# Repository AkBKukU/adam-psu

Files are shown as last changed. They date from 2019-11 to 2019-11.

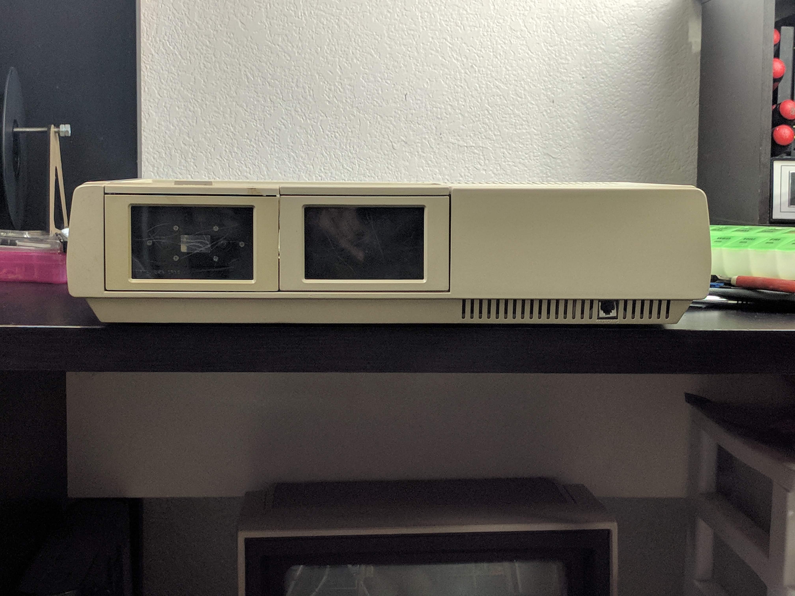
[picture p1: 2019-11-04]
doc/IMG_20191101_171837.jpg

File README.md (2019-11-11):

# Coleco Adam Internal PSU

The Coleco Adam originally shipped with a printer that contained the entire PSU 
for the device. It generated 12V, 5V, & -5V DC voltages for the system to run on.
Now it is increasingly difficult to find the printer to go along with the 
system. This renders them unusable.

This project is an internal PSU that can be mounted inside the standalone 
Coleco Adam. If you have an Expansion Module #3 version of the Adam, it can be
used outside of the system as well.

## Installation 

This part was designed specifically to be non-destructive and once you have an
assembled part, does not require any soldering. The DB9 connector on the standalone
Adam is on a small cabled PCB. This board mounts in place of that and you 
internally connect that cable to the new PSU. Optionally, you could cut or 
desolder the DB9 connector and directly bridge across to the available pads.

For use with the Expansion Module #3 version of the Adam, the board can be 
externally plugged into the system. Based on feedback, this is assumed to be 
a much less common model and the design hasn't been optimized for this use. You 
may need to extend the DB9 connection to have enough clearance. A solid DB9
male to female adapter is encouraged over a cable for its better current 
capacity. If you do opt to use a DB9 extension cable **make sure it is not a 
null modem cable!**. Pins 3 & 3 on a null modem cable are swapped which will 
swap 12V and 5V going to your system which will **severely damage** crucial 
components.

## Functionality

This power supply is fundamentally a multi voltage DC-DC regulator. It takes in
a 12V 3A power source and while passing through the 12V also generates 5V and
-5V. The system itself has the following maximum power ratings:

 - 5V - 2.75A
 - -5V - 0.2A
 - 12VI - 0.6A
 - 12VL - 0.3A

(*Taken from page 49 of the Adam Technical reference manual*)

The 12V rail is split between inductive and logic loads on the system side. `D1`
allows for potentially high voltages to be recirculated but due to the shared
ground at this time I'm not sure how useful this really is.

This power supply is capable of supplying the following with the DC-DC 
regulators:

 - 5V - 5A
 - -5V - 1A

These higher output capabilities combined with the ability to change the 12V 
external power source should allow all potential accessories to have sufficient 
power. The original maximum power rating is in total ~25.2W, using a 3A 12V 
AC-DC converter provides ample headroom for DC regulations losses.

## Design

This regulator is made using SMPS Buck regulators to reduce the 12V input to 5V 
and -5V. The -5V source is a standard buck regulators being used in a negative 
configuration. Care has been taken in the design and parts selection to maintain
as much efficiency as possible. Despite this there will be power dissipation 
still and the board layout has taken this into consideration providing large
copper pours where possible. Heat sinking should not be necessary as the parts
should be, on average, drawing less than half of their maximum current in 
addition to the PCB cooling.

The physical parts selection for this as well as the layout design has kept in 
mind the ability to hand solder the parts. However, outside of the I/O, all 
parts are SMD and go down to 0603 sized passives. It is recommend that you have
a solid background in soldering, but this is not an especially difficult SMD 
board to assemble. `U2`, is an SOIC-8 with a thermal pad which will likely be 
the part that will give beginners the most difficulty. Recommended steps are:

 - Lightly tin the thermal pad
 - Apply flux
 - Place the part down, checking orientation
 - Solder opposing corner pins
 - Apply heat to the underside of the board while also applying pressure to the 
   part
 - Finish soldering remaining pins

## Availability, BOM, and Ordering

I will be producing these indefinitely and making them available for purchase.
They will be available on my website once I have assembled and validated the 
design.

The BOM is stored as extra fields in the KiCad schematic and can be exported
from there. It is also included as a CSV file with the non-orderable parts 
removed.

I have also created BOMs on Digi-Key and Mouser as shared carts that you can 
order directly:

Digi-Key: https://www.digikey.com/short/p0tbzh
Mouser: https://www.mouser.com/ProjectManager/ProjectDetail.aspx?AccessID=6486fe3deb 

**BOM Errata**: For v0.1 boards R4 needs to be changed to 1k instead of `0k. 
The BOM carts have not been updated to reflect this yet.

The parts selection vary slightly between vendors. Equivalent performance low
cost parts were selected in each case.

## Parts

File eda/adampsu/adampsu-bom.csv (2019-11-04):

Reference | Quantity | Value | Footprint | Datasheet | dk | mfr | mouser | maxV | rating
C11 | 1 | 2200pF | Capacitor_SMD:C_0603_1608Metric_Pad1.05x0.95mm_HandSolder | https://api.kemet.com/component-edge/download/datasheet/C0603C222K5RAC7411.pdf | 399-17586-1-ND | C0603C222K5RAC7411 | 80-C0603C222K5R7411 | 50 | XR7
C12 | 1 | 22pF | Capacitor_SMD:C_0603_1608Metric_Pad1.05x0.95mm_HandSolder | http://datasheets.avx.com/X7RDielectric.pdf | 478-6204-1-ND | 06035C220JAT2A | 581-06035C220JAT2A | 50 | XR7
C16 C5 | 2 | 0.1uF | Capacitor_SMD:C_0603_1608Metric_Pad1.05x0.95mm_HandSolder | http://www.samsungsem.com/kr/support/product-search/mlcc/CL10F104ZB8NNNC.jsp | 1276-1012-2-ND | CL10F104ZB8NNNC | 603-CC603KRX7R9BB104 | 25 | XR7
C17 C18 C13 C19 C14 C20 | 6 | 22uF | Capacitor_SMD:C_1206_3216Metric_Pad1.42x1.75mm_HandSolder | ~ | 1276-6780-1-ND | EMK316ABJ226ML-T | 963-EMK316ABJ226ML-T
C2 C1 | 2 | 10uF |  | ~ | 490-10498-1-ND | GRM21BC81C106KE15L | 81-GRM21BC81C106KE5L
C3 | 1 | 100uF | Capacitor_Tantalum_SMD:CP_EIA-7343-30_AVX-N_Pad2.25x2.55mm_HandSolder | http://datasheets.avx.com/TAJ_AUTO.pdf | 1189-1659-1-ND | TAJD107K016TNJV | 581-TAJD107K016TNJV | 16 | XR7
C7 C4 | 2 | 4.7uF | Capacitor_SMD:C_1206_3216Metric_Pad1.42x1.75mm_HandSolder | https://ds.yuden.co.jp/TYCOMPAS/ut/detail?pn=UMK316AB7475KL-T%20%20&u=M | 490-14466-2-ND | GRM21BR71C475KE51L | 81-GRM21BR71C475KE1L | 50 | XR7
C8 C10 C15 | 3 | 0.01uF | Capacitor_SMD:C_0603_1608Metric_Pad1.05x0.95mm_HandSolder | https://api.kemet.com/component-edge/download/datasheet/C0603C103M5RACTU.pdf | 399-7842-1-ND | C0603C103M5RACTU | 80-C0603C103M5R |  | XR7
C9 C6 | 2 | 0.1uF | adampsu:C_0508_1220Metric_Pad1.40x1.15mm_HandSolder | https://search.murata.co.jp/Ceramy/image/img/A01X/G101/ENG/LLL216R71E104MA01-01.pdf | 490-4346-1-ND | LLL216R71E104MA01L | 81-LLL216R71E104MA1L | 25 | XR7
D1 D2 | 2 | D_Schottky | adampsu:D_SOD-128 | https://www.mouser.com/datasheet/2/916/PMEG4050EP-1320387.pdf | 1727-5842-1-ND | PMEG4050EP,115 | 963-EMK325B7226MM-TR | 40
J1 | 1 | Barrel_Jack_Switch | adampsu:BarrelJack_CUI_PJ-047AH_Horizontal | https://www.cuidevices.com/product/resource/pj-047ah.pdf | CP-047AH-ND | PJ-047AH | 490-PJ-047AH
J2 | 1 | Conn_2Rows-09Pins | Connector_PinHeader_2.54mm:PinHeader_2x05_P2.54mm_Vertical | ~ | 1849-1002-ND | PR20205VBDN
J3 | 1 | DB9_Female | Connector_Dsub:DSUB-9_Female_Vertical_P2.77x2.84mm_MountingHoles | http://www.assmann-wsw.com/fileadmin/datasheets/ASS_4885_CO.pdf | AE10928-ND | A-DF 09 PP/Z | 636-171-009-203L001
L1 L2 | 2 | 4.7uH | adampsu:L_11.5x10.3_H4.8 | http://productfinder.pulseeng.com/products/datasheets/P769.pdf | 553-3001-1-ND | PA4342.472NLT | 673-PA4342.472NLT |  | 15.5mOhm
PC1 | 1 | PlungerCap | adampsu:PlungerCap-4JWHT | https://www.digikey.com/product-detail/en/e-switch/4JWHT/EG1077-ND/45809 | EG1077-ND | 4JWHT | 612-4J-WH
Q1 | 1 | BUK7880-55A_CUX | Package_TO_SOT_SMD:SOT-223-3_TabPin2 | https://assets.nexperia.com/documents/data-sheet/BUK7880-55A.pdf | 1727-2222-1-ND | BUK7880-55A/CUX | 771-BUK7880-55A/CUX
R10 | 1 | 1.96k | Resistor_SMD:R_0603_1608Metric_Pad1.05x0.95mm_HandSolder | http://www.yageo.com/documents/recent/PYu-RC_Group_51_RoHS_L_10.pdf | 311-1.96KHRCT-ND | RC0603FR-071K96L | 603-RC0603FR-071K96L
R11 | 1 | 54.9k |  | ~ |  | CR0603-FX-5492ELF | 652-CR0603FX-5492ELF
R3 | 1 | 1k | Resistor_SMD:R_0603_1608Metric_Pad1.05x0.95mm_HandSolder | http://www.yageo.com/documents/recent/PYu-RC_Group_51_RoHS_L_10.pdf | 311-1.0KGRCT-ND | RC0603JR-071KL | 603-RC0603JR-071KL
R4 R1 R2 | 3 | 10k | Resistor_SMD:R_0603_1608Metric_Pad1.05x0.95mm_HandSolder | http://www.yageo.com/documents/recent/PYu-RC_Group_51_RoHS_L_10.pdf | 311-10KGRCT-ND | RC0603JR-0710KL | 603-RC0603JR-0710KL
R5 | 1 | 665k | Resistor_SMD:R_0603_1608Metric_Pad1.05x0.95mm_HandSolder | http://www.yageo.com/documents/recent/PYu-RC_Group_51_RoHS_L_10.pdf | 311-665KHRCT-ND | RC0603FR-07665KL | 603-RC0603FR-07665KL
R6 | 1 | 130k | Resistor_SMD:R_0603_1608Metric_Pad1.05x0.95mm_HandSolder | http://www.koaspeer.com/catimages/Products/RK73B/RK73B.pdf | 2019-RK73B1JTTD134JCT-ND | RK73B1JTTD134J | 660-RK73B1JTTD134J
R7 | 1 | 37.4k | Resistor_SMD:R_0603_1608Metric_Pad1.05x0.95mm_HandSolder | http://www.yageo.com/documents/recent/PYu-RC_Group_51_RoHS_L_10.pdf | 311-37.4KHRCT-ND | RC0603FR-0737K4L | 603-RC0603FR-0737K4L
R8 | 1 | 51.1 | Resistor_SMD:R_0603_1608Metric_Pad1.05x0.95mm_HandSolder | http://www.yageo.com/documents/recent/PYu-RC_Group_51_RoHS_L_10.pdf | 311-51.1HRCT-ND | RC0603FR-0751R1L | 603-RC0603FR-0751R1L
R9 | 1 | 10.2k | Resistor_SMD:R_0603_1608Metric_Pad1.05x0.95mm_HandSolder | https://www.seielect.com/catalog/sei-rmcf_rmcp.pdf | RMCF0603FT10K2CT-ND | RMCF0603FT10K2 | 667-ERJ-3EKF1022V
SW1 | 1 | 30V 300mA Latching Switch | adampsu:Switch-LC1258EENP | https://sten-eswitch-13110800-production.s3.amazonaws.com/system/asset/product_line/data_sheet/36/LC.pdf | EG5886-ND | LC1258EENP | 612-LC1258EENP
U1 | 1 | TPS561201 | Package_TO_SOT_SMD:SOT-23-6 | http://www.ti.com/lit/ds/symlink/tps561201.pdf | 296-47885-1-ND | TPS561201DDCR | TPS561201DDCR
U2 | 1 | TPS54531DDAR | Package_SO:TI_SO-PowerPAD-8_ThermalVias | http://www.ti.com/lit/ds/symlink/tps54531.pdf | 296-40801-2-ND | TPS54531DDAR | 595-TPS54531DDAR

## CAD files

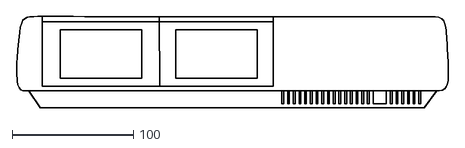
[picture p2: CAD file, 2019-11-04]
doc/adamart.dxf
356.6 x 75.1

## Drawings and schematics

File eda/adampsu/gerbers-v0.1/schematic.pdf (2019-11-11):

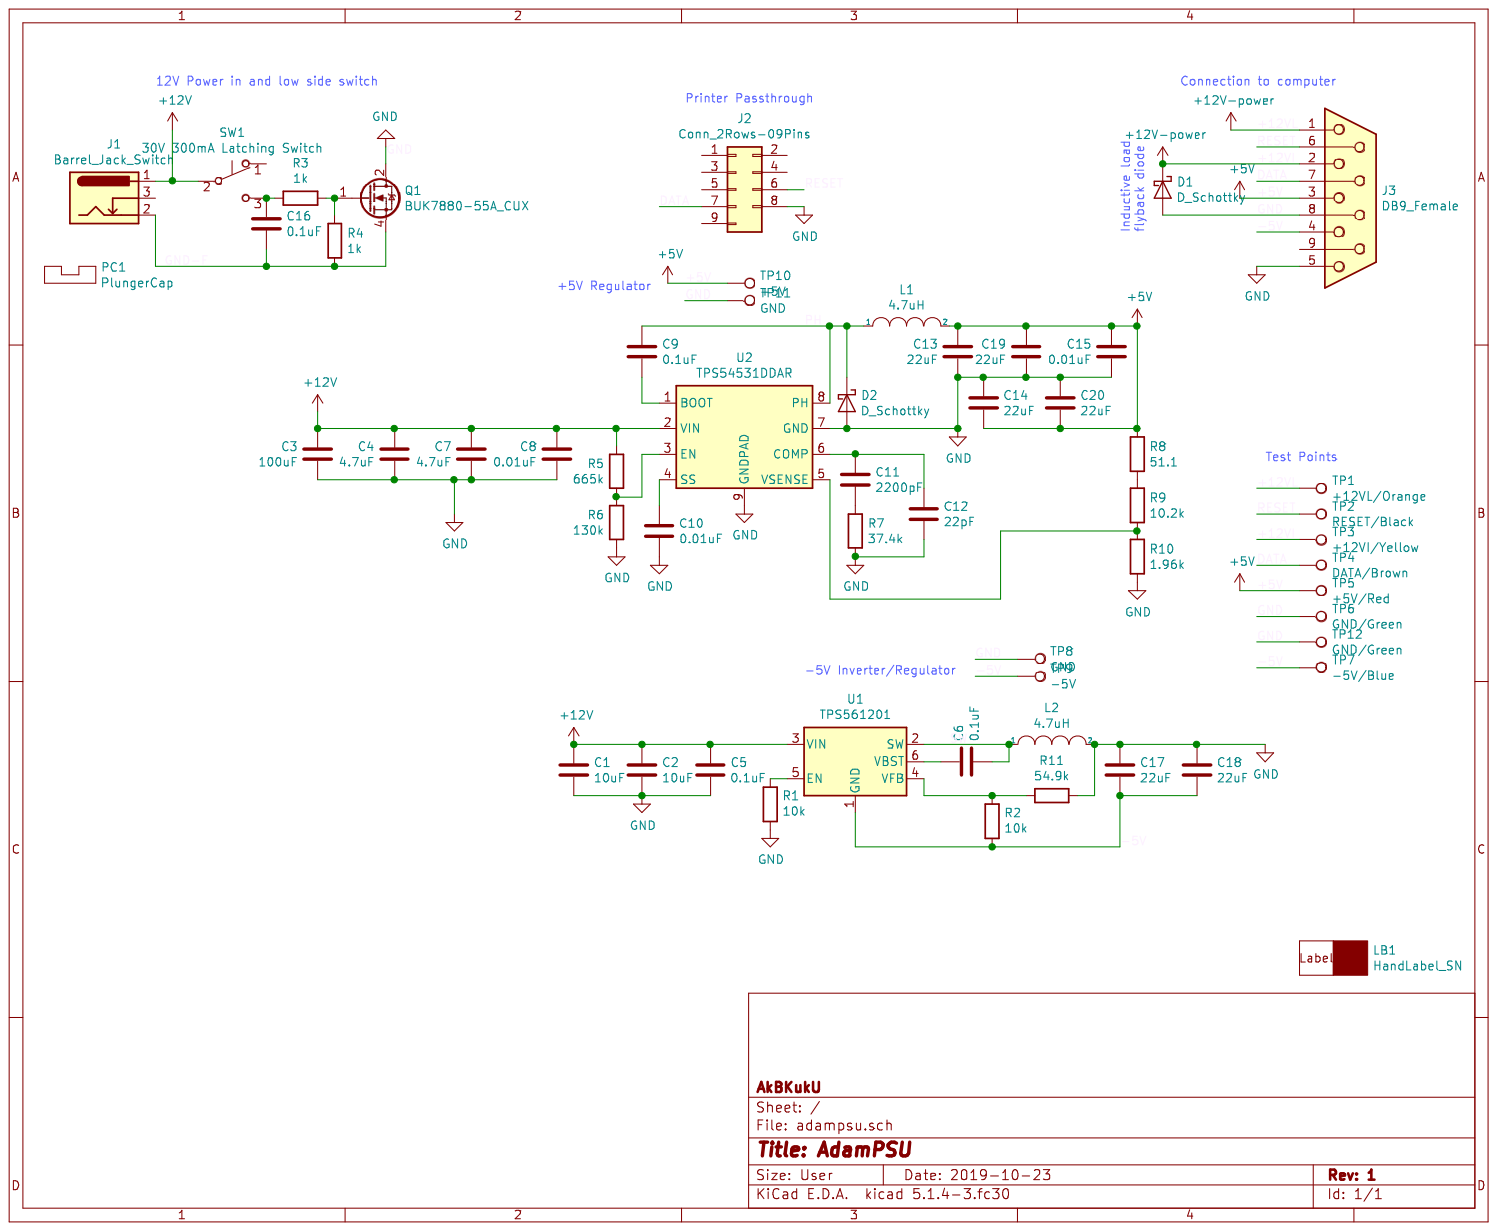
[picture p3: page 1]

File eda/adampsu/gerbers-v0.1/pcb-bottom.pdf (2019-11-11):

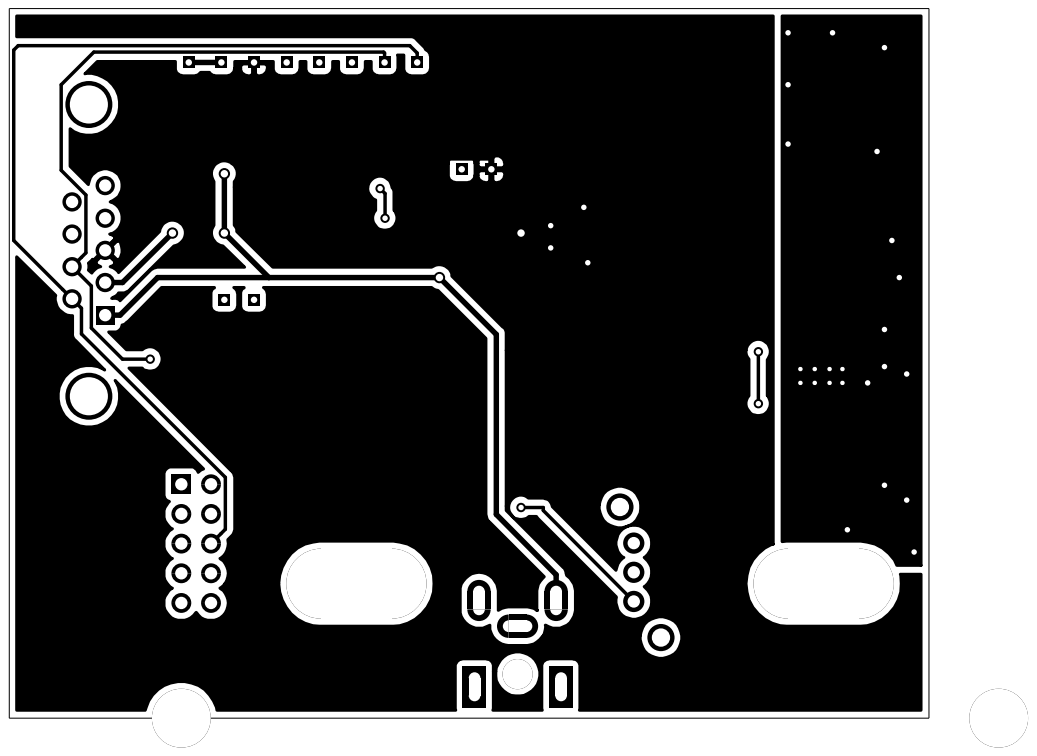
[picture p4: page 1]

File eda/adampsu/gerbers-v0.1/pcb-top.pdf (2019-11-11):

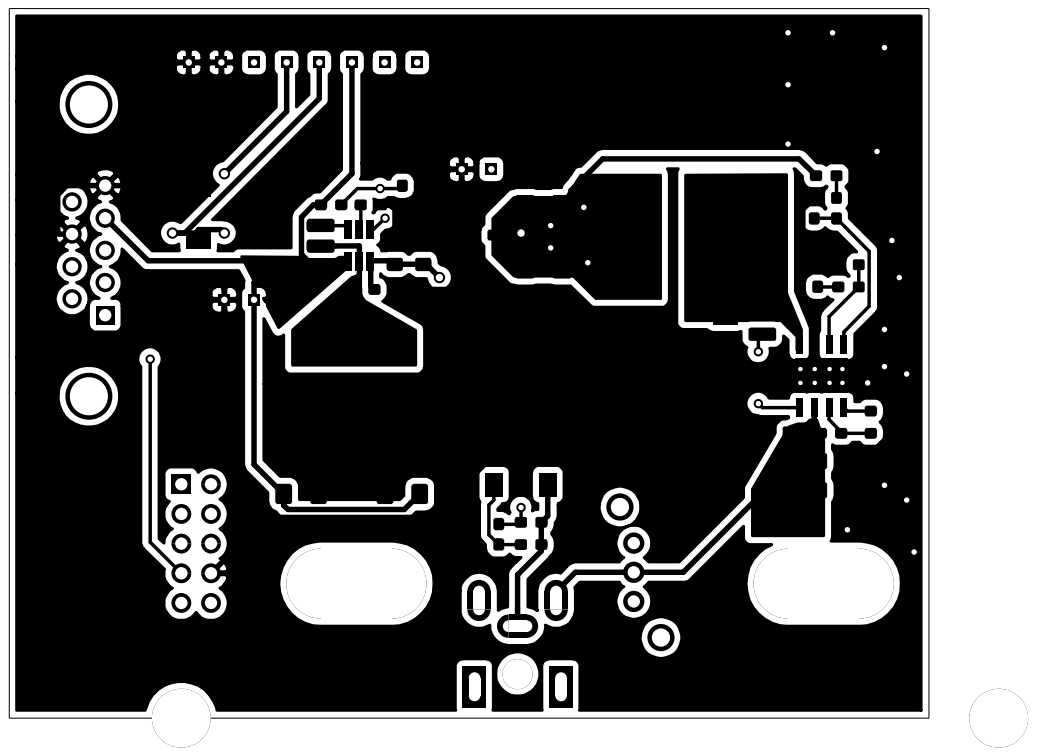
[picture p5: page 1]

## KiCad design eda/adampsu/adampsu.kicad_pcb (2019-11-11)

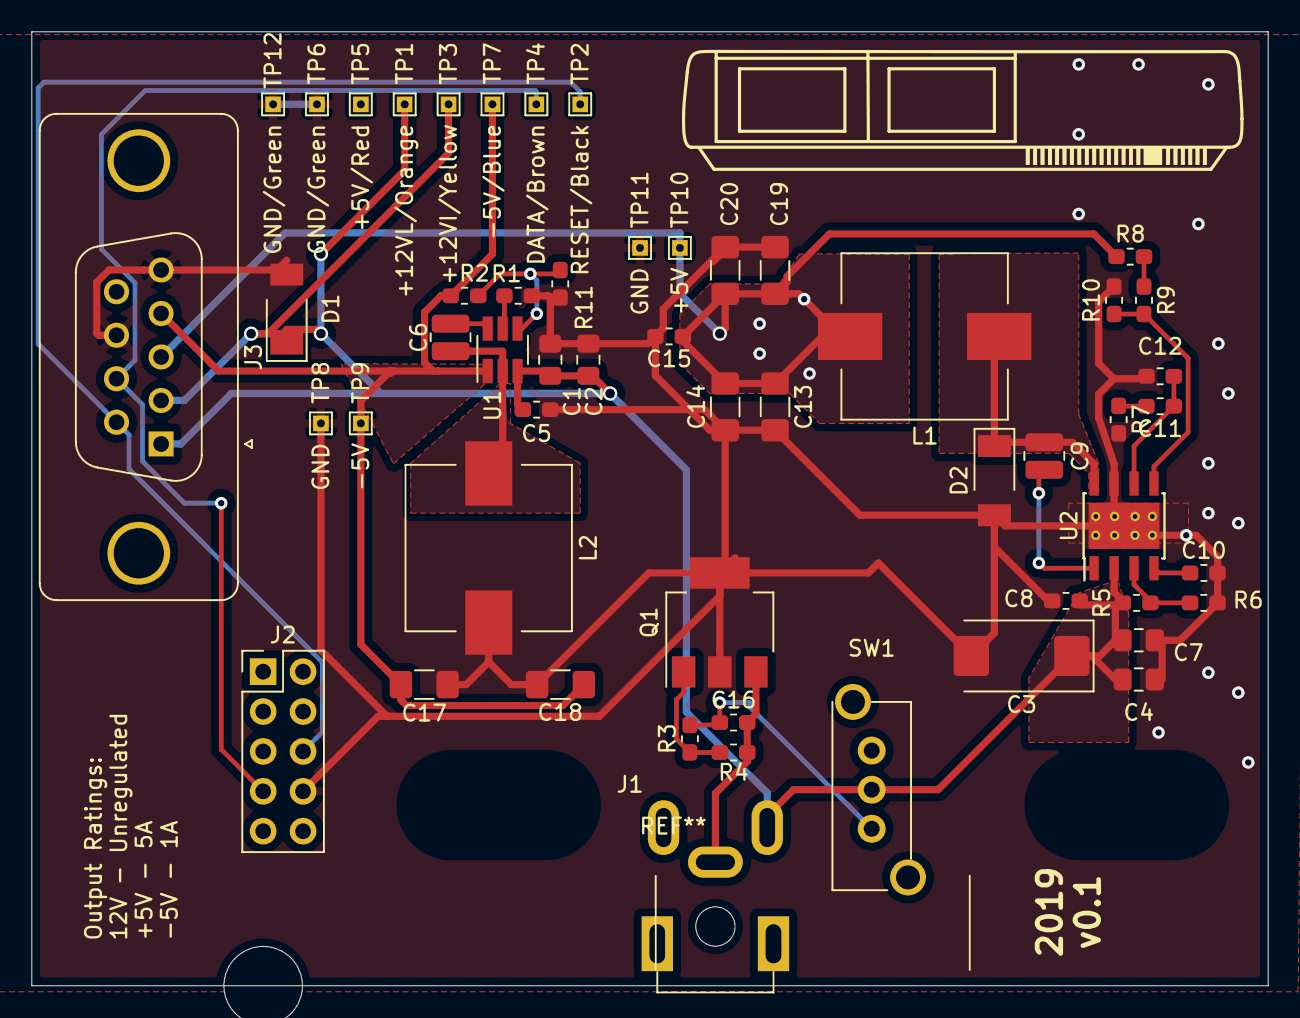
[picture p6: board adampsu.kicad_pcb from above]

Board: 2 copper layers, 78.7 x 60.8 mm, 56 parts (1 on the bottom side), 21 nets.

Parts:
C1, C2: 10uF; C_0805_2012Metric_Pad1.15x1.40mm_HandSolder
C3: 100uF; CP_EIA-7343-43_Kemet-X_Pad2.25x2.55mm_HandSolder
C4, C7: 4.7uF; C_0805_2012Metric_Pad1.15x1.40mm_HandSolder
C5, C16: 0.1uF; C_0603_1608Metric_Pad1.05x0.95mm_HandSolder
C6, C9: 0.1uF; C_0508_1220Metric_Pad1.40x1.15mm_HandSolder
C8, C10, C15: 0.01uF; C_0603_1608Metric_Pad1.05x0.95mm_HandSolder
C11: 2200pF; C_0603_1608Metric_Pad1.05x0.95mm_HandSolder
C12: 22pF; C_0603_1608Metric_Pad1.05x0.95mm_HandSolder
C13, C14, C17, C18, C19, C20: 22uF; C_1206_3216Metric_Pad1.42x1.75mm_HandSolder
D1, D2: D_Schottky; D_SOD-128
J1: Barrel_Jack_Switch; BarrelJack_CUI_PJ-047AH_Horizontal
J2: Conn_2Rows-09Pins; PinHeader_2x05_P2.54mm_Vertical
J3: DB9_Female; DSUB-9_Female_Vertical_P2.77x2.84mm_MountingHoles
L1, L2: 4.7uH; L_11.5x10.3_H4.8
LB1: HandLabel_SN; adamlabel
PC1: PlungerCap; PlungerCap-4JWHT
Q1: BUK7880-55A_CUX; SOT-223-3_TabPin2
R1, R2, R4: 10k; R_0603_1608Metric_Pad1.05x0.95mm_HandSolder
R3: 1k; R_0603_1608Metric_Pad1.05x0.95mm_HandSolder
R5: 665k; R_0603_1608Metric_Pad1.05x0.95mm_HandSolder
R6: 130k; R_0603_1608Metric_Pad1.05x0.95mm_HandSolder
R7: 37.4k; R_0603_1608Metric_Pad1.05x0.95mm_HandSolder
R8: 51.1; R_0603_1608Metric_Pad1.05x0.95mm_HandSolder
R9: 10.2k; R_0603_1608Metric_Pad1.05x0.95mm_HandSolder
R10: 1.96k; R_0603_1608Metric_Pad1.05x0.95mm_HandSolder
R11: 54.9k; R_0603_1608Metric_Pad1.05x0.95mm_HandSolder
SW1: 30V 300mA Latching Switch; Switch-LC1258EENP
TP1: +12VL/Orange; TestPoint_Labeled
TP2: RESET/Black; TestPoint_Labeled
TP3: +12VI/Yellow; TestPoint_Labeled
TP4: DATA/Brown; TestPoint_Labeled
TP5: +5V/Red; TestPoint_Labeled
TP6, TP12: GND/Green; TestPoint_Labeled
TP7: -5V/Blue; TestPoint_Labeled
TP8, TP11: GND; TestPoint_Labeled
TP9: -5V; TestPoint_Labeled
TP10: +5V; TestPoint_Labeled
U1: TPS561201; SOT-23-6_Handsoldering
U2: TPS54531DDAR; TI_SO-PowerPAD-8_ThermalVias

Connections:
+5V: C13.1, C14.2, C15.1, C19.1, C20.2, J3.3, L1.2, R8.1, TP5.1, TP10.1
+12V: C1.1, C2.1, C3.1, C4.1, C5.1, C7.1, C8.1, D1.1, J1.1, J3.1, J3.2, R5.1, SW1.2, TP1.1, TP3.1, U1.3, U2.2
/-5V: C17.2, C18.2, J3.4, R2.1, TP7.1, TP9.1, U1.1
/DATA: J2.7, J3.7, TP4.1
/GND-F: C16.2, J1.2, Q1.3, R4.2
/PH: C9.1, D2.1, L1.1, U2.8
/RESET: J2.6, J3.6, TP2.1
/SW: C6.2, L2.1, U1.2
GND: C1.2, C2.2, C3.2, C4.2, C5.2, C7.2, C8.2, C10.2, C12.2, C13.2, C14.1, C15.2, C17.1, C18.1, C19.2, C20.1, D1.2, D2.2, J2.8, J3.5, J3.8, L2.2, Q1.2, R1.1, R6.2, R7.2, R10.2, R11.1, TP6.1, TP8.1, TP11.1, TP12.1, U2.7, U2.9
unnamed: C6.1, U1.6
unnamed: C9.2, U2.1
unnamed: C10.1, U2.4
unnamed: C11.1, C12.1, U2.6
unnamed: C11.2, R7.1
unnamed: C16.1, R3.2, SW1.3
unnamed: Q1.1, R3.1, R4.1
unnamed: R1.2, U1.5
unnamed: R5.2, R6.1, U2.3
unnamed: R8.2, R9.1
unnamed: R9.2, R10.1, U2.5
unnamed: R2.2, R11.2, U1.4

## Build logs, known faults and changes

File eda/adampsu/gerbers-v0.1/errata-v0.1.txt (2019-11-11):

 
 - Revision needed- 
U2 Power pad not exposed on bottom for manual assembly
R1 connects to GND instead of +12V preventing U1 from turning on
All touch points too small
SW1 power switch on position reversed
SW1 power switch needs more clearance to depress switch

 - Resolvable / non-functional - 
R4 Power switch FET Gate pull down needs to be 1k
R7 RefDes under C11
bottom label text duplicated
C6 1 <-> U1 6 trace width narrow
Q1 Power switch FET detaches GND but non-isolated PSU may still provide a current path

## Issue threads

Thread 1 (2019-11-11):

Q1 Nch FET does not turn off leaving system always on

AkBKukU, 2019-11-11:
The BUK7880 Nch FET in Q1 being used as a low side switch works when tested with individual rails (tested up to 300mA) allowing the 12V PSU GND to be isolated. When installed in the computer it does not fully turn off though allowing the system to stay on.

Vds when on is ~55mV
Vds when off is 12V

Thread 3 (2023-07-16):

v0.1 Errata

AkBKukU, 2023-07-16:
- Board edge knock out
 - Label on bottom duplicated
 - TPs too small
 - cap doesn't fit switch
 - R4 10k -> 1k
 - Neg Reg Enable needs to connet to Vin
 - No exposed pad for lower regulator thermal pad
 - low side switching bad

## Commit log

2019-10-22 Schematic complete
    [adampsu.kicad_pcb, adampsu.sch]
2019-10-27 BOM completeled but using expensive LDO
    [adampsu.kicad_pcb, adampsu.sch]
2019-10-28 switch to buck regulator. Need to choose parts
    [adampsu.sch]
2019-10-28 Final parts selection finished
    [adampsu.kicad_pcb, adampsu.sch]
2019-10-31 board layout started, but need new -5V regulator
    [adampsu-bom.csv, adampsu.kicad_pcb, adampsu.sch]
2019-10-31 using non-inverting buck for negative, too expensive though
    [adampsu.sch]
2019-11-10 Add board errata after initial assembly.
2019-11-11 Export schematic and PCB to PDFs
    [adampsu.kicad_pcb, adampsu.sch]
